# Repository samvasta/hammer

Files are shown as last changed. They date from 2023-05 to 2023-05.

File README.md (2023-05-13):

# Hammer

It is tradition for blacksmiths to build their own tools.

In building their tool set, the smith practices their craft and gains a deeper understanding of each tool - what went into its production, how and why it functions. The smith's hammer is built to fit the smith's hands and meet their needs exactly.

The smith's hammer may not make them a better smith, but does make their craft more enjoyable.

This *my* hammer.

---

This repository contains information about the *hardware*. There may be several different branches to support variations of the hammer.

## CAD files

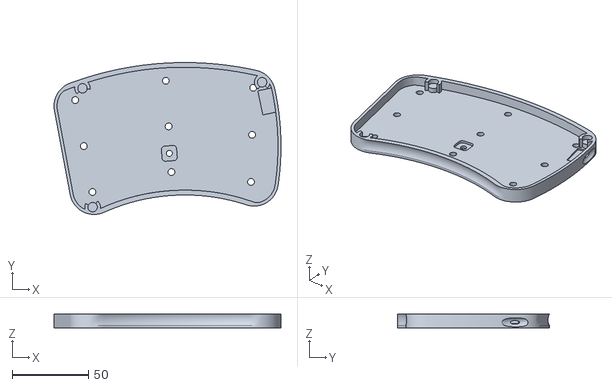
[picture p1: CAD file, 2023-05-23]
case/Bottom.stl
148.9 x 99.6 x 9.00

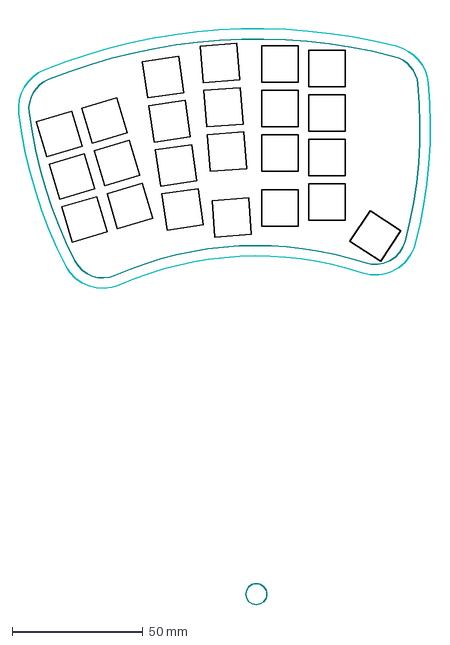
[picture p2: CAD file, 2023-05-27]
plate/fusion_import.dxf
159.4 x 224.8 mm

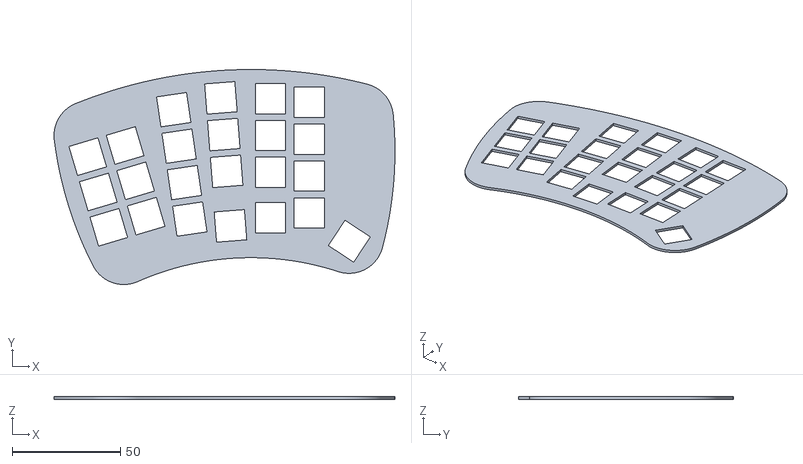
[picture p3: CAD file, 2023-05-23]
case/Top.stl
157.5 x 99.3 x 1.20

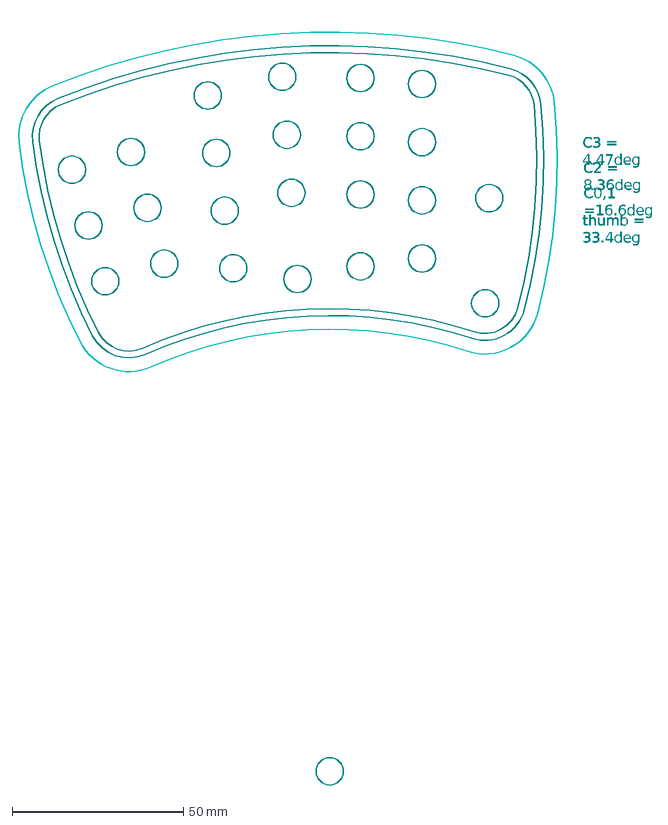
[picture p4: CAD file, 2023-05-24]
plate/kicad_import.dxf
C3 = 4.47deg
C2 = 8.36deg
C0,1 =16.6deg
thumb = 33.4deg

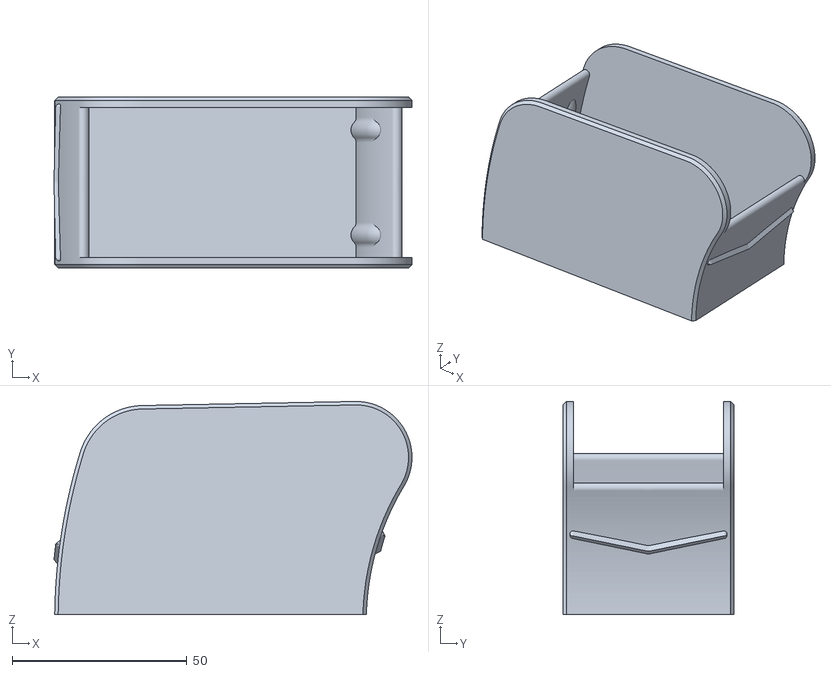
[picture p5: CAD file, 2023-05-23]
case/Case (Test Fit).stl
102.4 x 49.0 x 61.0

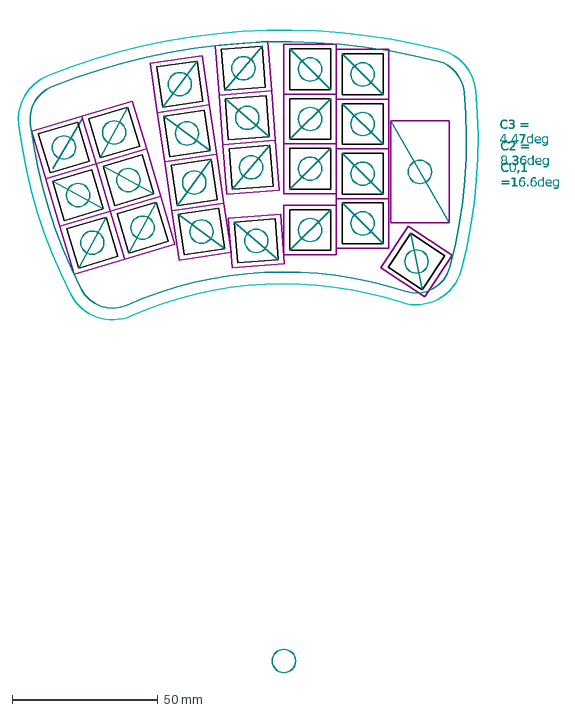
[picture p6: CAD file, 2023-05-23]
plate/isolated_minimal.dxf
C3 = 4.47deg
C2 = 8.36deg
C0,1 =16.6deg

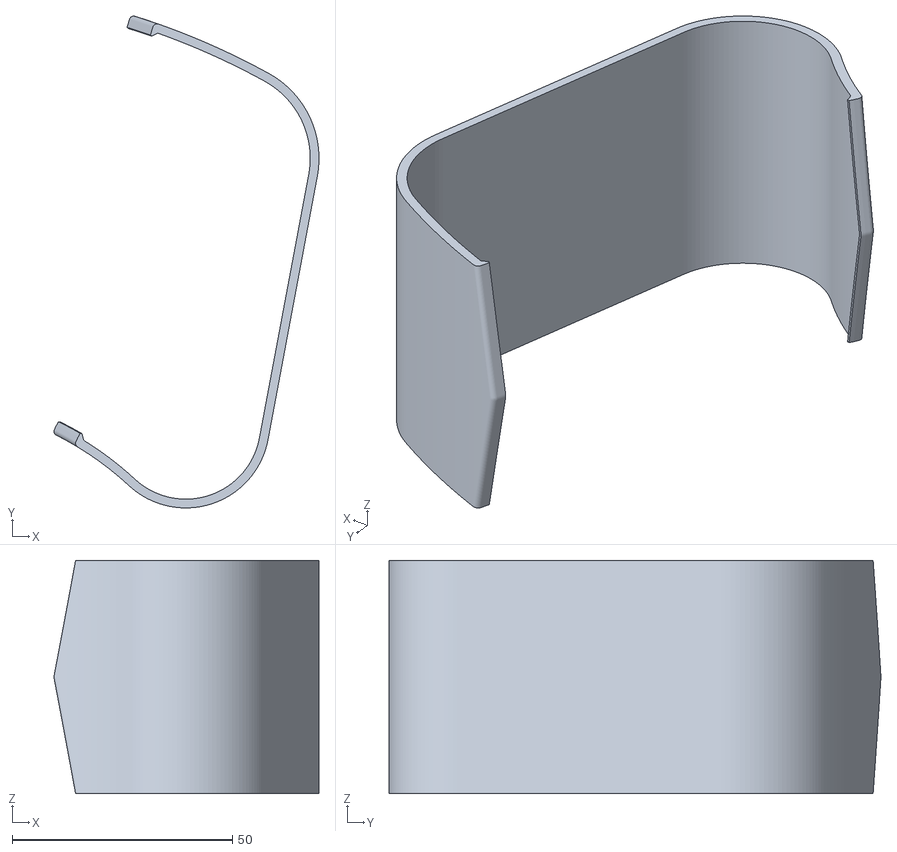
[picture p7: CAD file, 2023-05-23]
case/Clip (Test Fit).stl
60.2 x 111.7 x 53.0

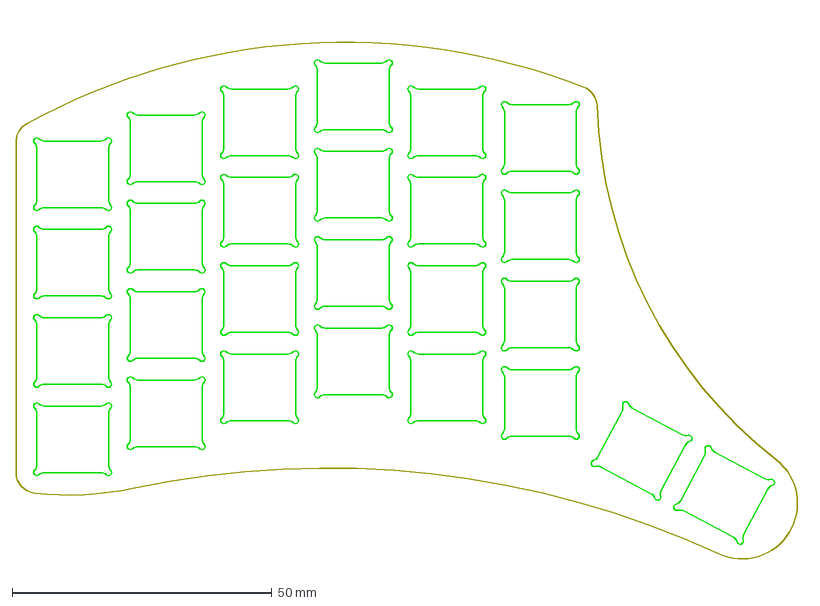
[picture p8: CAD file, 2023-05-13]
plate/top_plate.dxf
151.6 x 105.7 mm

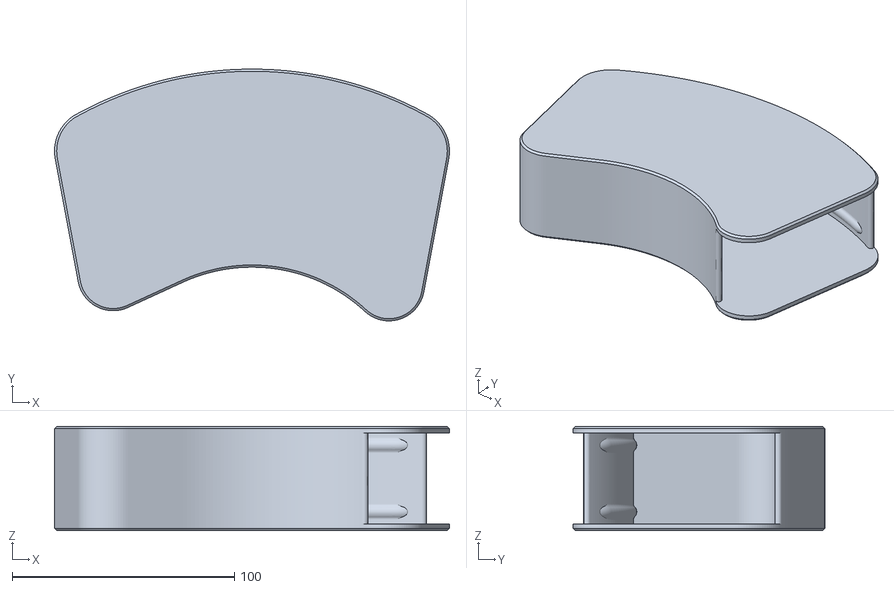
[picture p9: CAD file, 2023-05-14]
case/Case.stl
177.8 x 113.3 x 47.0

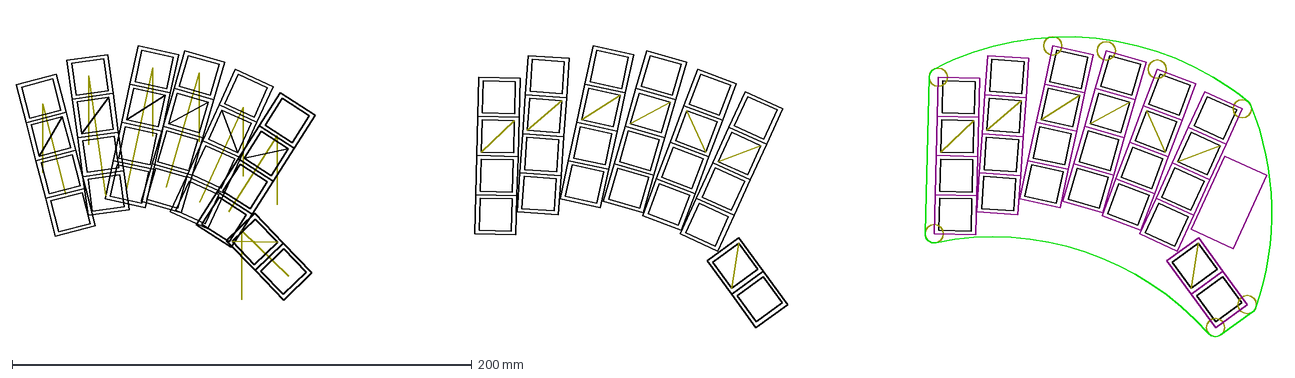
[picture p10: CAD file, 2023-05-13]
plate/top_plate_minimal.dxf
549.4 x 139.9 mm

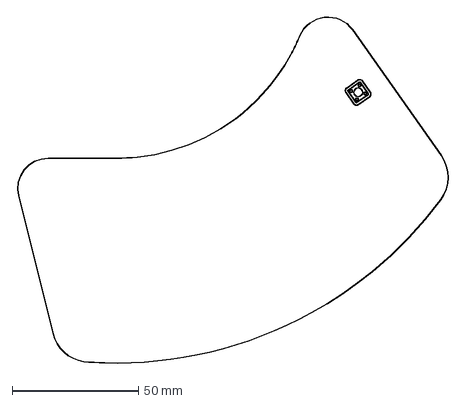
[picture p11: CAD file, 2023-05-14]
case/button.dxf
172.1 x 137.9 mm

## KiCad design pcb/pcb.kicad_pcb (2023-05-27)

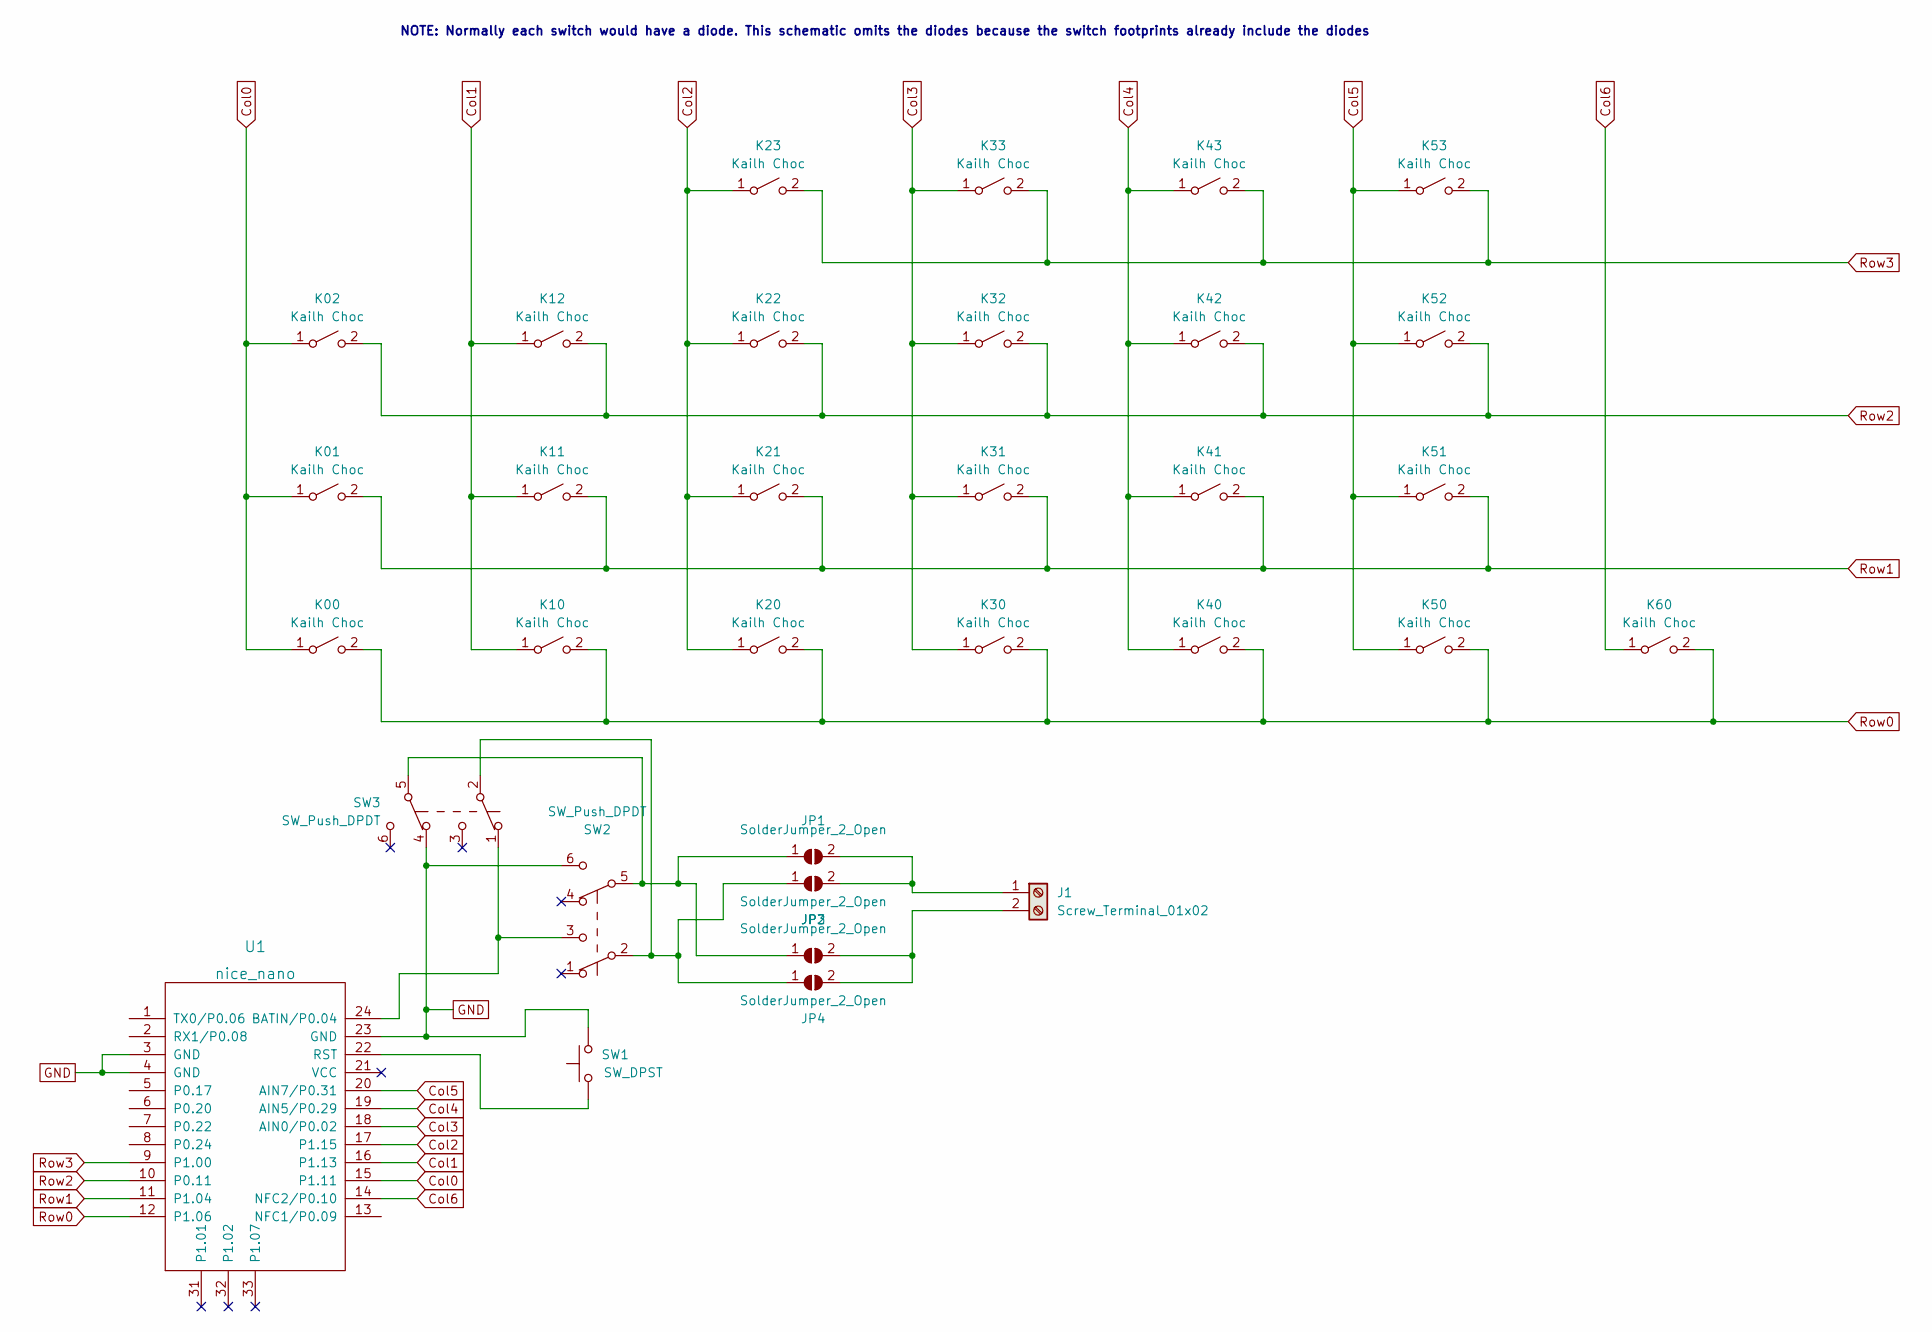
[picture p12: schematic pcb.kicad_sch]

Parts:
J1: Screw_Terminal_01x02; JST_PH_S2B-PH-K_1x02_P2.00mm_Horizontal
JP1, JP2, JP3, JP4: SolderJumper_2_Open; SolderJumper-2_P1.3mm_Open_TrianglePad1.0x1.5mm
K00, K01, K02, K10, K11, K12, K20, K21, K22, K23, K30, K31, K32, K33, K40, K41, K42, K43, K50, K51, K52, K53, K60: Kailh Choc; Kailh_socket_PG1350_reversible
SW1: SW_DPST; SW_PUSH_6mm
SW2, SW3: SW_Push_DPDT; SW_JS202011SCQN (Reverse Mount)
U1: nice_nano; DIP-24_W15.24mm_Socket

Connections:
Col0: K00.1 (A), K01.1 (A), K02.1 (A), U1.15 (P1.11)
Col1: K10.1 (A), K11.1 (A), K12.1 (A), U1.16 (P1.13)
Col2: K20.1 (A), K21.1 (A), K22.1 (A), K23.1 (A), U1.17 (P1.15)
Col3: K30.1 (A), K31.1 (A), K32.1 (A), K33.1 (A), U1.18 (AIN0/P0.02)
Col4: K40.1 (A), K41.1 (A), K42.1 (A), K43.1 (A), U1.19 (AIN5/P0.29)
Col5: K50.1 (A), K51.1 (A), K52.1 (A), K53.1 (A), U1.20 (AIN7/P0.31)
Col6: K60.1 (A), U1.14 (NFC2/P0.10)
GND: SW1.2, SW2.6 (C), SW3.4 (A), U1.3 (GND), U1.4 (GND), U1.23 (GND)
unnamed: J1.1, JP1.2 (B), JP2.2 (B)
unnamed: J1.2, JP3.2 (B), JP4.2 (B)
unnamed: JP1.1 (A), JP3.1 (A), SW2.5 (B), SW3.5 (B)
unnamed: JP2.1 (A), JP4.1 (A), SW2.2 (B), SW3.2 (B)
unnamed: SW1.1, U1.22 (RST)
unnamed: SW2.3 (C), SW3.1 (A), U1.24 (BATIN/P0.04)
Row0: K00.2 (B), K10.2 (B), K20.2 (B), K30.2 (B), K40.2 (B), K50.2 (B), K60.2 (B), U1.12 (P1.06)
Row1: K01.2 (B), K11.2 (B), K21.2 (B), K31.2 (B), K41.2 (B), K51.2 (B), U1.11 (P1.04)
Row2: K02.2 (B), K12.2 (B), K22.2 (B), K32.2 (B), K42.2 (B), K52.2 (B), U1.10 (P0.11)
Row3: K23.2 (B), K33.2 (B), K43.2 (B), K53.2 (B), U1.9 (P1.00)

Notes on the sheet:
NOTE: Normally each switch would have a diode. This schematic omits the diodes because the switch footprints already include the diodes

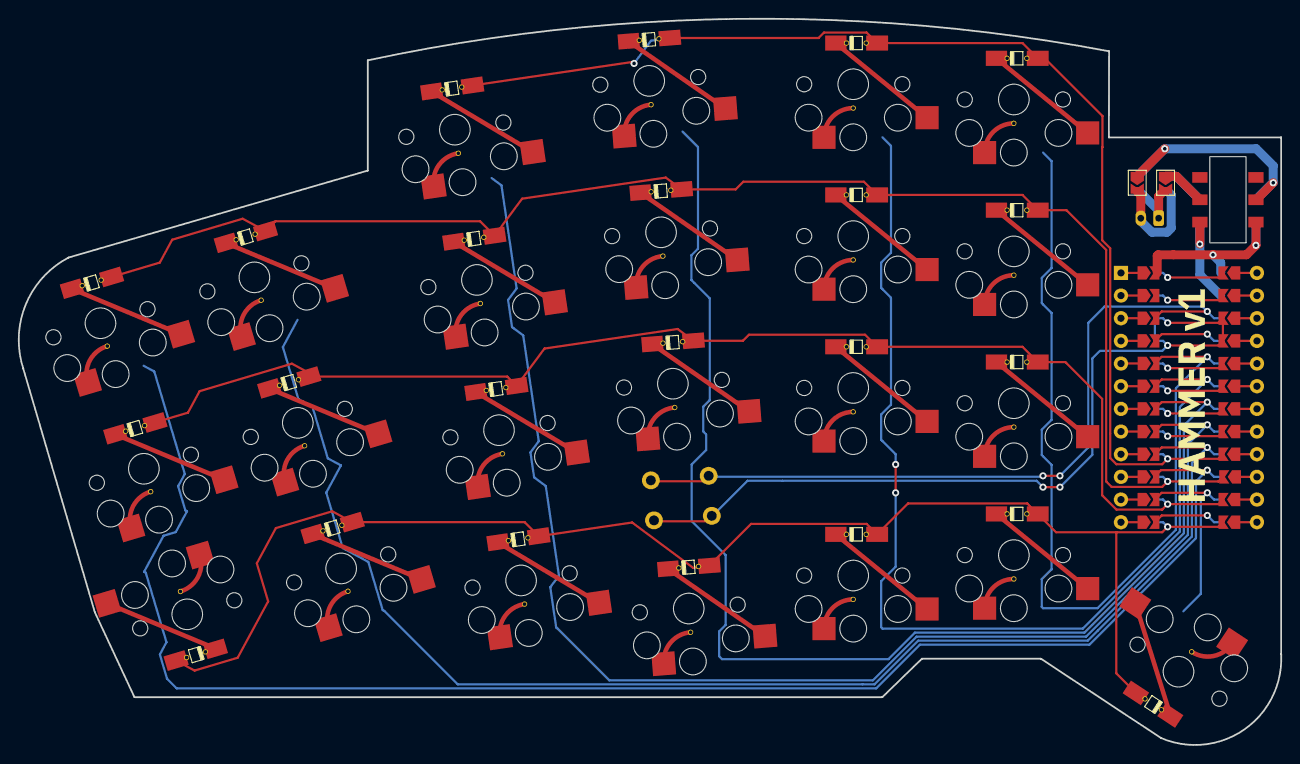
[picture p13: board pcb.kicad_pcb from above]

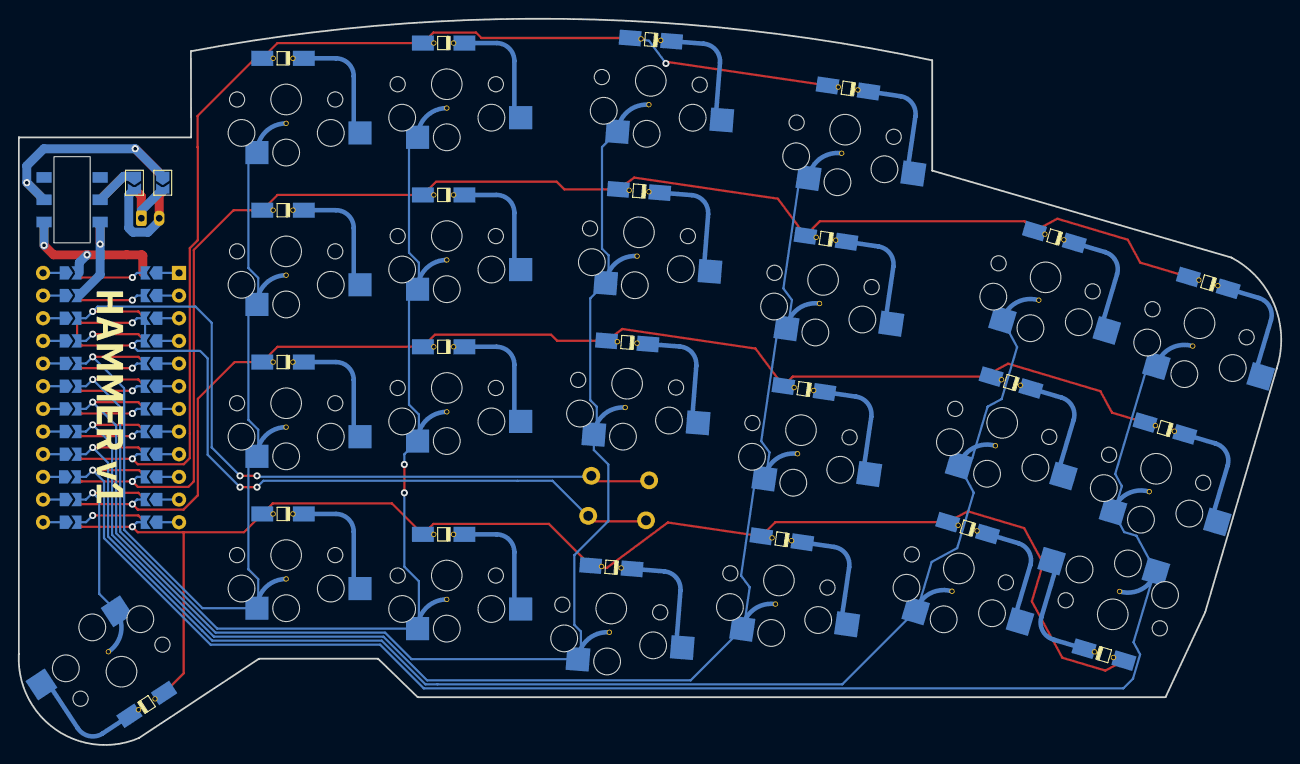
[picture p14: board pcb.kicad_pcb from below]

Board: 2 copper layers, 141.5 x 81.4 mm, 32 parts (4 on the bottom side), 18 nets.

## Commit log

2023-05-13 init kicad project & start on layout
    [isolated_minimal.dxf, pcb.kicad_pcb, pcb.kicad_sch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]
2023-05-13 more layout changes
    [isolated_minimal.dxf]
2023-05-13 nice shape
    [isolated_minimal.dxf]
2023-05-14 first pass at pcb and case
    [Bottom.stl, Case.stl, Top.stl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]
2023-05-20 refining the shape
    [fusion_import.dxf, isolated_minimal.dxf, kicad_import.dxf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]
2023-05-23 playing around with layouts & shapes
    [Bottom.stl, Case (Test Fit).stl, Clip (Test Fit).stl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]
2023-05-24 update pcb for new shape
    [kicad_import.dxf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]
2023-05-27 update pcb
    [fusion_import.dxf, pcb.kicad_pcb, pcb.kicad_sch]
2023-05-27 update project to kicad 7
    [pcb.kicad_pcb, pcb.kicad_sch]
